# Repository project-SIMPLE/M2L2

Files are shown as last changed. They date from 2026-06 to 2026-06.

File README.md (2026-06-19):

# M2L2 — SIMPLE Project

**Mobile Metaverse Learning Lab (M2L2)** is an open-source, self-contained box housing VR headsets and a server, designed to make deploying immersive learning experiences in classrooms as simple as possible.

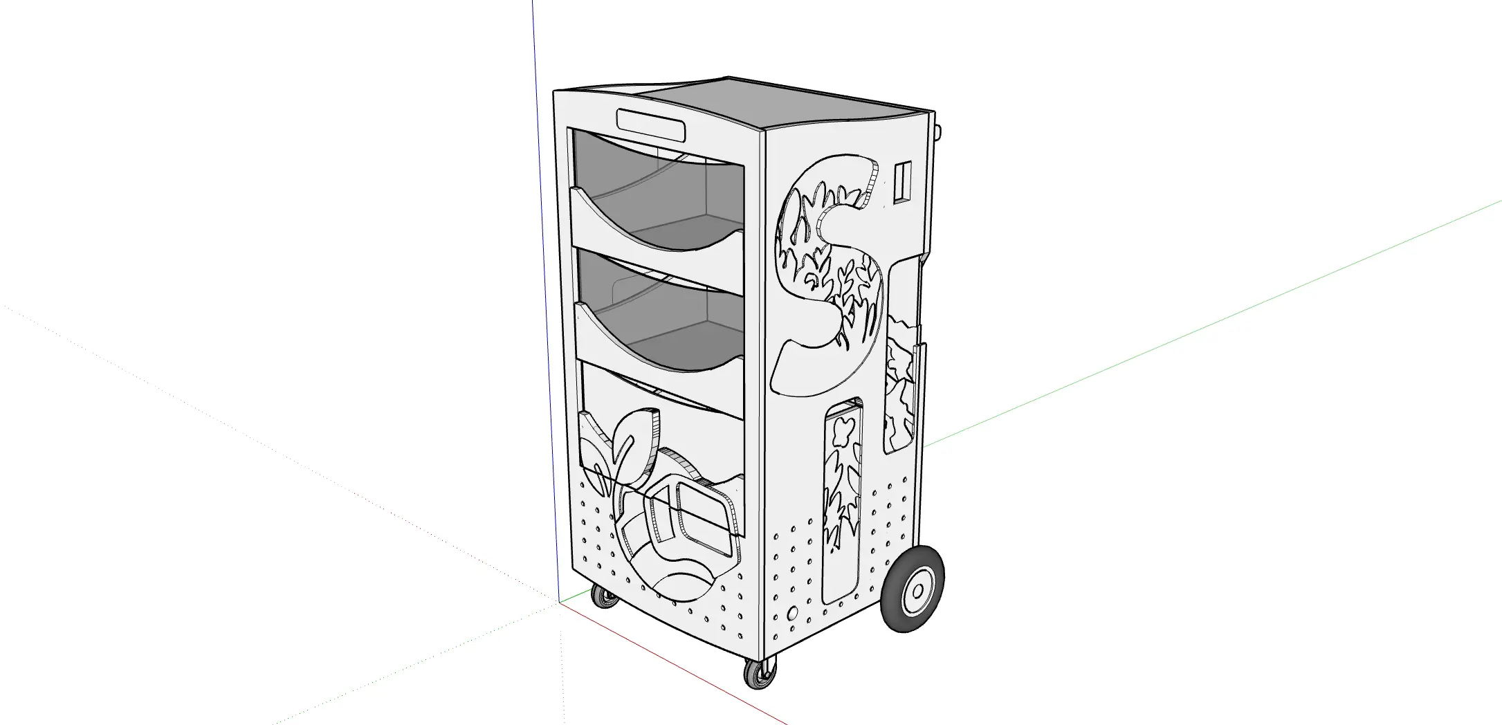
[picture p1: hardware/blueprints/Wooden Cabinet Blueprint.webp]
Blueprint view


---

## Repository Structure

```
m2l2/
├── hardware/ # Blueprints, BOM, assembly guides, and component specs
└── software/ # Mac Mini setup and configuration tools (zsh scripts, etc.)
```

- **[hardware/](./hardware/)** — Everything you need to build or replicate the physical M2L2 box.
- **[software/](./software/)** — Tools to provision the recommended Mac Mini to run the SIMPLE project.

---

## Getting Started

1. **Build the box** — Follow the [hardware guide](./hardware/README.md) to assemble your M2L2 unit.
2. **Set up the server** — Use the [software setup tools](./software/README.md) to configure the Mac Mini.
3. **Deploy** — You're ready to bring VR into the classroom!

---

## Contributing

Contributions are welcome! Please open an issue or submit a pull request. See [CONTRIBUTING.md](./CONTRIBUTING.md) for guidelines.

---

## Acknowledgments

The latest iteration of the M2L2 enclosure was designed and built by [Legacy Handmade](https://www.legacytayho.com/).

---

## License

This project is open-source. See [LICENSE](./LICENSE) for details.

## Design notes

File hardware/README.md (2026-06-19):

# Hardware — M2L2 Box

This folder contains all the hardware documentation required to build, replicate, or maintain the **M2L2** box — a self-contained unit housing VR headsets and a server, designed for easy deployment of the [SIMPLE project](https://github.com/project-simple) in classroom environments.

Blueprint view

---

## Folder Structure

```
hardware/
├── blueprints/ # Cabinet drawings and mechanical plans
├── bom/ # Bill of Materials (BOM)
└── assembly/ # Step-by-step assembly guide
```

---

## What's in the Box

The M2L2 box is designed to be a plug-and-play classroom kit. It typically includes:

- **VR Headsets** — Pre-configured for the SIMPLE project
- **Server (Mac Mini)** — Runs the SIMPLE project software
- **Networking equipment** — Local network switch/router for headset connectivity
- **Power distribution** — PDU or power strip for all devices
- **Enclosure** — The physical box housing all components

> Refer to the [BOM](./bom/) for exact part references, quantities, and sourcing.

---

## Blueprints

The [`blueprints/`](./blueprints/) directory contains the cabinet drawings and mechanical plans (dimensions, cutouts, internal layout):

- `Wooden Cabinet Blueprint.pdf`

> The latest M2L2 enclosure was designed and built by [Legacy Handmade](https://www.legacytayho.com/).

---

## Bill of Materials (BOM)

See [`bom/`](./bom/) for the full parts list including:

- Part names and descriptions
- Recommended suppliers and part numbers
- Quantities per unit
- Estimated costs

---

## Assembly

Step-by-step assembly instructions are in [`assembly/`](./assembly/README.md). The guide covers headset preparation, cabinet preparation, and the internal power/network/display wiring. Follow the sections in order to avoid rework.

---

## Notes

- Always power off the unit before performing any hardware maintenance.
- Ensure adequate ventilation around the Mac Mini to prevent thermal throttling.
- VR headsets should be stored in their designated slots to avoid cable damage.

---

## Contributing

If you improve the hardware design (better cable management, new enclosure version, etc.), please open a pull request with updated blueprints and a revised BOM. See the root [CONTRIBUTING.md](../CONTRIBUTING.md) for guidelines.

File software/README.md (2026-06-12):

# Software — Mac Mini Setup Tools

This folder contains configuration and setup tools for the **Mac Mini** recommended to run the [SIMPLE project](https://github.com/project-simple) as part of the M2L2.

> **This is not the SIMPLE project's application source code.**
> These are environment setup tools (shell scripts, dotfiles, etc.) to provision a Mac Mini from a clean macOS install into a ready-to-run SIMPLE project host.

---

## Folder Structure

```
software/
├── scripts/ # setup and startup scripts (.command)
│ ├── Installation_script.command
│ └── startup_script.command
├── docs/ # setup guides and troubleshooting
│ ├── macmini_configuration.md
│ ├── wifi_router_configuration.md
│ ├── headset_configuration.md
│ ├── installation_instructions.md
│ ├── startup_script_instructions.md
│ └── BE25_firmware_update.md
└── BE25_firmware_v1.7.bin # bundled router firmware
```

---

## Prerequisites

Before running any scripts, make sure you have:

- A **Mac mini** running a supported version of macOS (pinned to **Sequoia 15.7.5**; see [Mac mini configuration](./docs/macmini_configuration.md))
- An **admin user account**
- An active internet connection (for the initial package installs only — the deployed box runs offline)

---

## Quick Start

Provision the box in this order. Each step links to its detailed guide:

1. **Configure the WiFi router** — SSID, password, and firmware:
   [WiFi router configuration](./docs/wifi_router_configuration.md).
2. **Configure the Mac mini** — initial setup, app install, auto-start, and system settings:
   [Mac mini configuration](./docs/macmini_configuration.md).
   - Installs Homebrew, Node.js, ADB, and the WebPlatform via the [installation script](./docs/installation_instructions.md).
   - Sets the WebPlatform to launch on boot via the [startup script](./docs/startup_script_instructions.md).
3. **Configure the headsets** — developer mode, USB debugging, and fixed IPs:
   [Headset configuration](./docs/headset_configuration.md).

Once all three are done, the box boots straight into the WebPlatform player screen with all six headsets reachable on `M2L2_WIFI`.

---

## Contributing

Improvements to setup scripts are welcome! Please test changes on a clean macOS install before submitting a pull request. See the root [CONTRIBUTING.md](../CONTRIBUTING.md) for guidelines.

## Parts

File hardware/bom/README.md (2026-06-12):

# Bill of Materials — M2L2 Box

Complete parts list to build one **M2L2 (Mobile Metaverse Learning Lab)** unit: a self-contained, classroom-deployable kit running the [SIMPLE project](https://github.com/project-SIMPLE) stack.

> **Pricing note:** Prices are indicative (mid-2026). Big-ticket items in USD (US retail), locally sourced items in VND. Verify with your suppliers before ordering. Meta raised Quest 3 prices in April 2026; the 128GB model is discontinued.

---

### 1. Compute & VR

| # | Item | Ref / Model | Qty | Est. unit price | Subtotal | Notes |
|---|---|---|-----|---|---|---|
| 1.1 | VR headset | Meta Quest 3 — 512GB | 6 | $600 | $3,600 | Includes 2× Touch Plus controllers each. 512GB is the only variant since April 2026. |
| 1.2 | Head strap (+ battery) | BOBOVR M3 Pro | 6 | $40 | $240 | Halo strap with swappable B100 battery — comfort + extended runtime for back-to-back classroom sessions. The Carina D1 still charges the headset with the strap mounted, but **not** the strap battery (charge B100 packs separately via USB-C). |
| 1.3 | Server | Apple Mac mini (Apple Silicon, 16GB RAM / 512GB SSD min.) | 1 | $799 | $799 | Runs WebPlatform + GAMA + headset management. Pin macOS version per software setup guide (UPS control is OS-version sensitive). |
| 1.4 | Teacher tablet | Apple iPad (current base model, WiFi) | 1 | $349 | $349 | Client for the teacher dashboard (WebPlatform UI) over the local network. Any recent iPad works. |

### 2. Power

| # | Item | Ref / Model | Qty | Est. unit price | Subtotal | Notes |
|---|---|---|-----|---|---|---|
| 2.1 | UPS | APC Back-UPS BX2200MI-MS (2200VA / 1200W) | 1 | $250 | $250 | USB-HID monitored by the M2L2 UPS library for graceful shutdown. `-MS` = universal sockets variant. |
| 2.2 | Charging dock | PrismXR Carina D1 (Quest 3) | 6 | $80 | $480 | One dock per headset, charging at 30W. Each ships with its own fast-charge adapter and cable. Also charges Touch Plus controllers via contact pads (rechargeable batteries + contact battery covers included). |
| 2.3 | Power strip | Điện Quang ECO ĐQ ESK 5BR 8ECO — 8 outlets, 5m, 2500W max, breaker | 1 | 192.000 ₫ (~$8) | ~$8 | Plugs into UPS battery outlets; 8 slots and 2500W rating cover all 6 dock adapters + Mac mini + router simultaneously. Do **not** chain a surge protector behind the UPS. |
| 2.4 | USB-C cables | UGREEN US535 (90440) — USB-C to USB-C, 240W, 2m | 6 | $13 | $78 | ADB/management link to the Mac mini and backup wired charging. Any replacement must support ≥45W (headset max draw). |

### 3. Networking

| # | Item | Ref / Model | Qty | Est. unit price | Subtotal | Notes |
|---|---|---|-----|---|---|---|
| 3.1 | WiFi router | TP-Link Deco BE25 (WiFi 7) | 1 | $95 | $95 | Dedicated SSID for headsets. No internet uplink required — fully offline LAN. Ethernet cable for the Mac mini link is included in the box. |

### 4. Peripherals & Display

| # | Item | Ref / Model | Qty | Est. unit price | Subtotal | Notes |
|---|---|---|-----|---|---|---|
| 4.1 | USB-C hub | HyperDrive Next Dual 4K HDMI 7-in-1 | 1 | $150 | $150 | Used for its dual HDMI outputs (4K60 + 4K30) and its USB-A port, which connects the UPS USB-HID monitoring link to the Mac mini. |
| 4.2 | HDMI cables | UGREEN 10107 — HDMI, 2m | 2 | $10 | $20 | Internal runs: hub HDMI outputs enclosure panel couplers (4.3). |
| 4.3 | Keyboard + touchpad | Logitech K400 Plus Touch | 1 | $30 | $30 | Wireless all-in-one input for on-site Mac mini administration — no separate mouse or desk space needed. |

### 5. Enclosure & Mechanical

| # | Item | Ref / Model | Qty | Est. unit price | Subtotal | Notes |
|---|---|---|-----|---|---|---|
| 5.1 | Enclosure | **Custom build** — see [`blueprints/`](../blueprints/) | 1 | per blueprints | — | Materials, dimensions, and cutting plans are documented in the blueprints folder. Sized for the BX2200MI tower (~15kg) plus all components; total kit weight exceeds 25kg, plan for wheels/handles accordingly. |
| 5.2 | Cable management | Velcro straps, cable ties, adhesive mounts (assorted) | 1 | $15 | $15 | |
| 5.3 | Panel-mount plate | 3-slot wall-mount plate with 2× HDMI female (F/F) couplers | 1 | $12 | $12 | Mounted on the enclosure: exposes both HDMI outputs externally so the projector/screen plugs into the box without opening it. Third slot spare (blank or future port). |

## 6. Accessories & Consumables

| # | Item | Ref / Model | Qty | Est. unit price | Subtotal | Notes |
|---|---|---|-----|---|---|---|
| 6.1 | Hygiene face covers | Silicone facial interface cover (Quest 3 compatible) | 6 | $15 | $90 | Wipeable — required for shared classroom use. |
| 6.2 | Cleaning kit | Microfiber cloths + lens-safe wipes | 1 | $15 | $15 | Never use alcohol wipes on lenses. |
| 6.3 | Stickers | Custom-printed SIMPLE project stickers, numbered 1–6 | 1 set | $15 | $15 | Printed per project artwork. Headset number WebPlatform device identity; label headsets, controllers, and docks consistently. |

---

## Total estimated cost

| Category | Subtotal |
|---|---|
| 1. Compute & VR | $4,988 |
| 2. Power | $816 |
| 3. Networking | $95 |
| 4. Peripherals & Display | $212 |
| 5. Enclosure & Mechanical | $15 + custom enclosure (see blueprints) |
| 6. Accessories & Consumables | $120 |
| **Total per M2L2 unit** | **≈ $6,246 + enclosure materials** |

---

## Substitution guidance

- **Headsets** — the SIMPLE Unity template targets Meta Horizon OS; Quest 3S (128GB, $350) is a functional drop-in that cuts ~$1,500 per box at the cost of lens/resolution quality. Pair with the Carina **D1S** dock variant and the BOBOVR **S3** strap line. Lower-cost non-Meta alternatives are under active investigation (see project roadmap).
- **Server** — any Apple Silicon Mac mini works; avoid Intel models (UPS control library uses IOKit HID paths validated on Apple Silicon).
- **Power strip** — any 8-outlet strip rated ≥2500W with a breaker is acceptable; the Điện Quang reference is a locally sourced (Vietnam) part.
- **USB-C cables** — any e-marked USB-C cable supporting ≥45W works; 240W-rated cables chosen for headroom and durability.
- **Teacher tablet** — any device with a modern browser can run the dashboard; the iPad is the validated reference client.

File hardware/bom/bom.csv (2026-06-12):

id | category | item | model | qty | unit_price | currency | subtotal_usd_approx | notes
1.1 | Compute & VR | VR headset | Meta Quest 3 512GB | 6 | 600 | USD | 3600 | Includes 2x Touch Plus controllers each; 512GB only variant since April 2026
1.2 | Compute & VR | Head strap (battery) | BOBOVR M3 Pro | 6 | 40 | USD | 240 | Halo strap with swappable B100 battery; Carina D1 charges headset with strap mounted but not the strap battery
1.3 | Compute & VR | Server | Apple Mac mini (Apple Silicon; 16GB RAM / 512GB SSD min.) | 1 | 799 | USD | 799 | Runs WebPlatform + GAMA + headset management; pin macOS version per software setup guide
1.4 | Compute & VR | Teacher tablet | Apple iPad (current base model; WiFi) | 1 | 349 | USD | 349 | Client for the teacher dashboard over local network
2.1 | Power | UPS | APC Back-UPS BX2200MI-MS (2200VA / 1200W) | 1 | 250 | USD | 250 | USB-HID monitored for graceful shutdown; -MS = universal sockets
2.2 | Power | Charging dock | PrismXR Carina D1 (Quest 3) | 6 | 80 | USD | 480 | One dock per headset @30W; own adapter + cable included; charges controllers via contact pads (rechargeable batteries included)
2.3 | Power | Power strip | Dien Quang ECO DQ ESK 5BR 8ECO (8 outlets; 5m; 2500W; breaker) | 1 | 192000 | VND | 8 | Plugs into UPS battery outlets; covers all dock adapters + Mac mini + router; no surge protector behind UPS
2.4 | Power | USB-C cables | UGREEN US535 90440 (USB-C to USB-C; 240W; 2m) | 6 | 13 | USD | 78 | ADB/management + backup wired charging; replacement must support >=45W (headset max)
3.1 | Networking | WiFi router | TP-Link Deco BE25 (WiFi 7) | 1 | 95 | USD | 95 | Dedicated SSID for headsets; fully offline LAN; Ethernet cable included in box
4.1 | Peripherals & Display | USB-C hub | HyperDrive Next Dual 4K HDMI 7-in-1 | 1 | 150 | USD | 150 | Used for dual HDMI outputs (4K60 + 4K30) and USB-A port connecting the UPS USB-HID monitoring link to the Mac mini
4.2 | Peripherals & Display | HDMI cables | UGREEN 10107 (HDMI; 2m) | 2 | 10 | USD | 20 | Internal runs: hub HDMI outputs to enclosure panel couplers (4.3)
4.3 | Peripherals & Display | Keyboard + touchpad | Logitech K400 Plus Touch | 1 | 30 | USD | 30 | Wireless all-in-one input for on-site Mac mini administration
5.1 | Enclosure & Mechanical | Enclosure | Custom build - see blueprints/ | 1 |  |  |  | Materials and plans documented in blueprints folder; kit weight >25kg
5.2 | Enclosure & Mechanical | Cable management | Velcro straps + cable ties + adhesive mounts | 1 | 15 | USD | 15
5.3 | Peripherals & Display | Panel-mount plate | 3-slot wall-mount plate with 2x HDMI female (F/F) couplers | 1 | 12 | USD | 12 | Mounted on enclosure; exposes both HDMI outputs externally; third slot spare
6.1 | Accessories & Consumables | Hygiene face covers | Silicone facial interface cover (Quest 3 compatible) | 6 | 15 | USD | 90 | Wipeable; required for shared classroom use
6.2 | Accessories & Consumables | Cleaning kit | Microfiber cloths + lens-safe wipes | 1 | 15 | USD | 15 | No alcohol wipes on lenses
6.3 | Accessories & Consumables | Stickers | Custom-printed SIMPLE project stickers numbered 1-6 | 1 | 15 | USD | 15 | Headset number maps to WebPlatform device identity; label headsets/controllers/docks
TOTAL |  |  |  |  |  |  | 6246 | Approx USD mid-2026 excluding custom enclosure materials; verify regional pricing

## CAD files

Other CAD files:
hardware/blueprints/Wooden Cabinet Blueprint.skp

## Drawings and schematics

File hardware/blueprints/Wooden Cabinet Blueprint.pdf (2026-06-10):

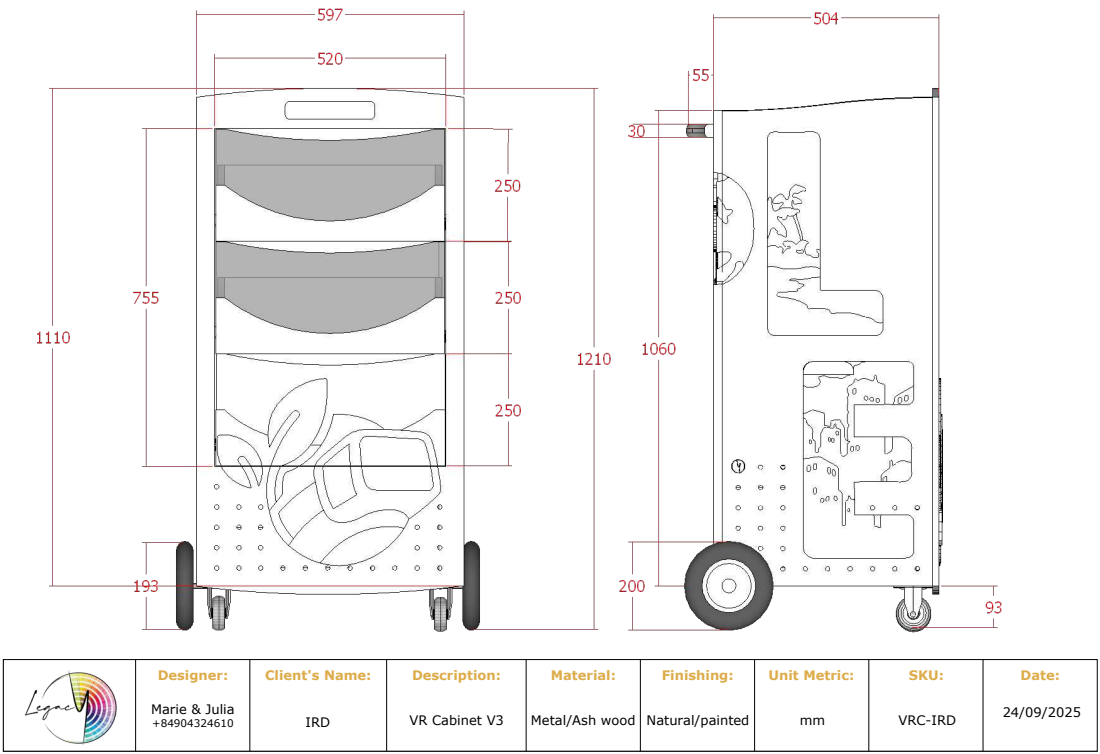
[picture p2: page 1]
Marie & Julia; Designer:; Client's Name:; Description:; Material:; Finishing:; Unit Metric:; SKU:; Date:; IRD; VR Cabinet V3; Metal/Ash wood; Natural/painted; VRC-IRD

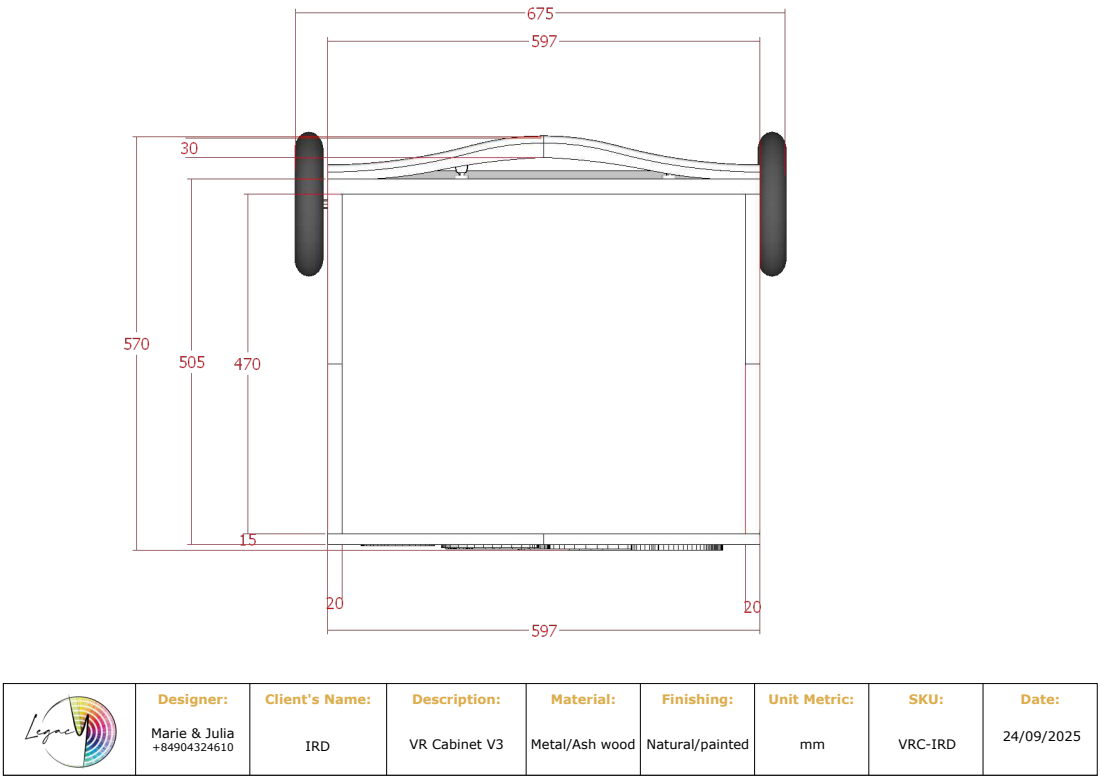
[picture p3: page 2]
Designer:; Client's Name:; Description:; Material:; Finishing:; Unit Metric:; SKU:; Date:

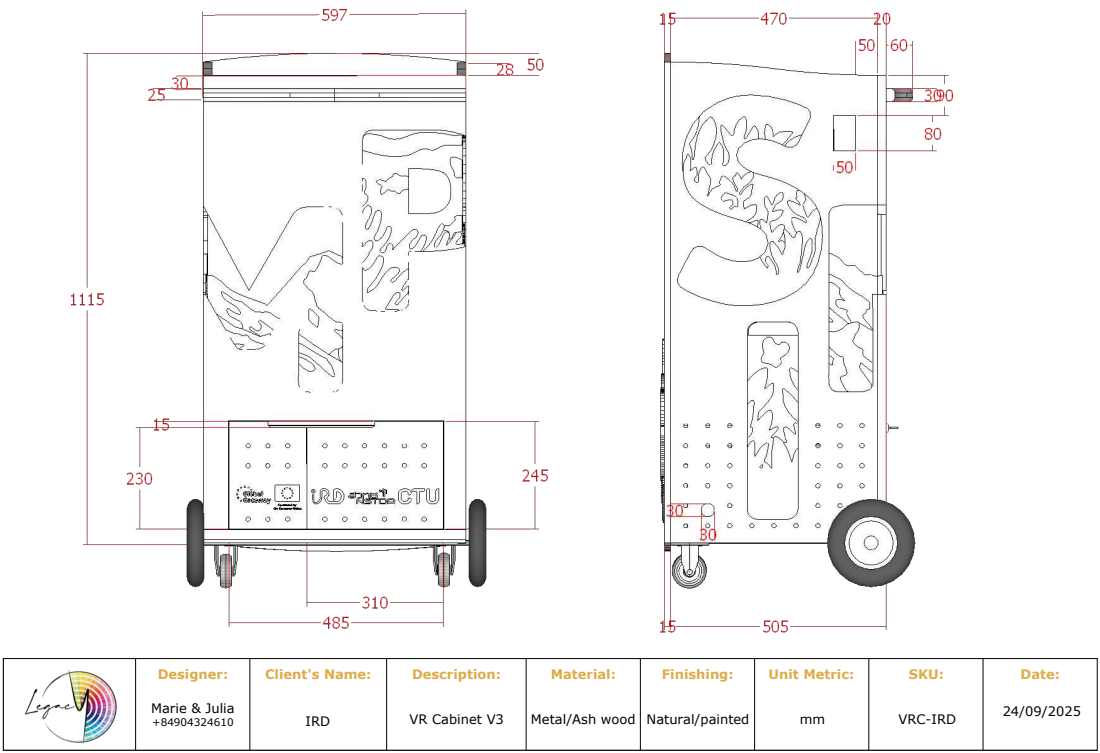
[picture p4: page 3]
Designer:; Client's Name:; Description:; Material:; Finishing:; Unit Metric:; SKU:; Date:

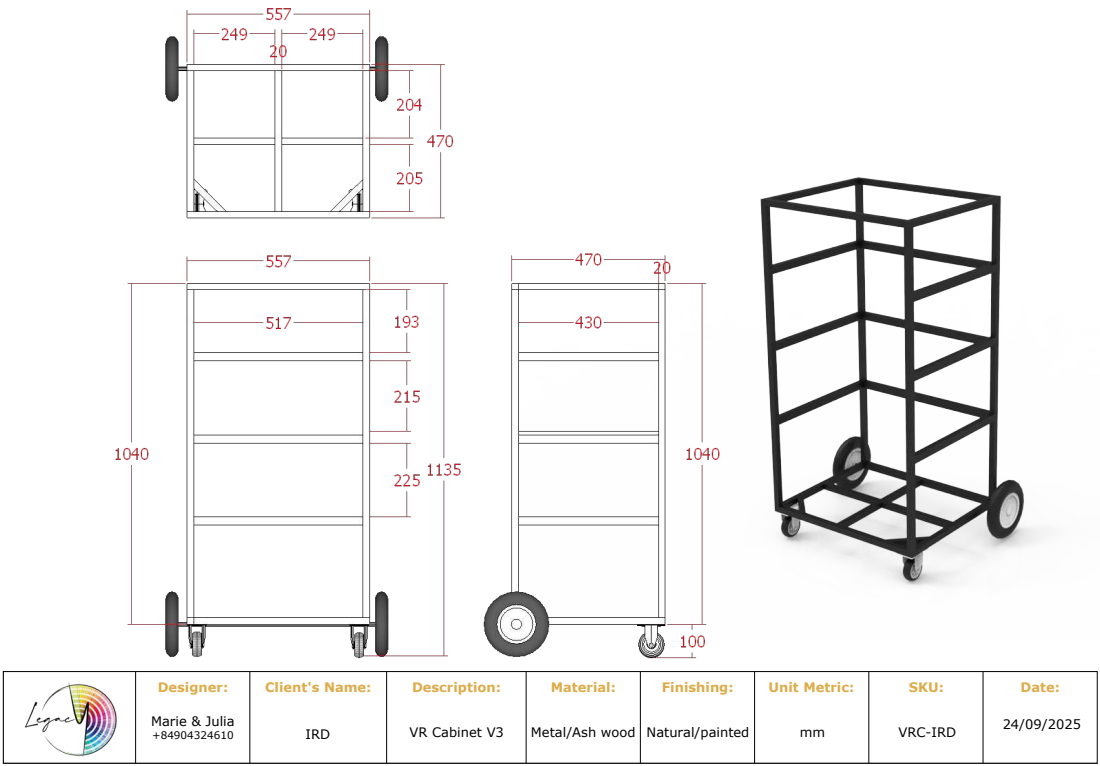
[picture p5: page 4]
Designer:; Client's Name:; Description:; Material:; Finishing:; Unit Metric:; SKU:; Date:

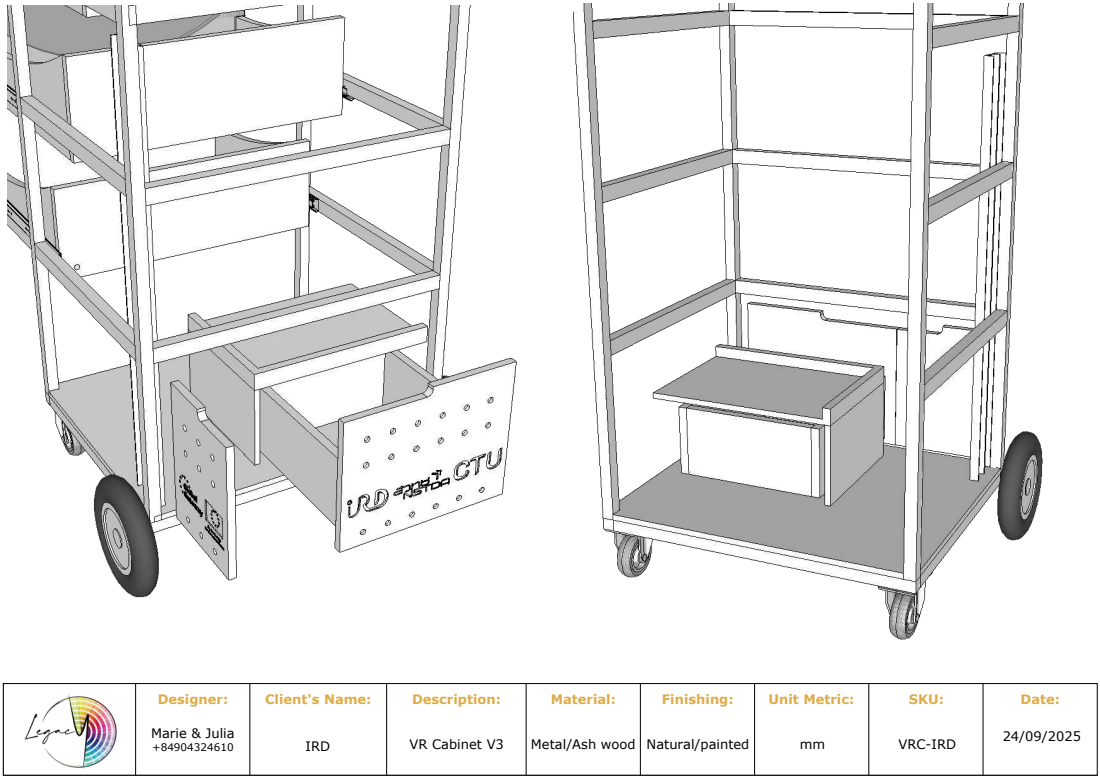
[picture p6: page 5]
Designer:; Client's Name:; Description:; Material:; Finishing:; Unit Metric:; SKU:; Date:

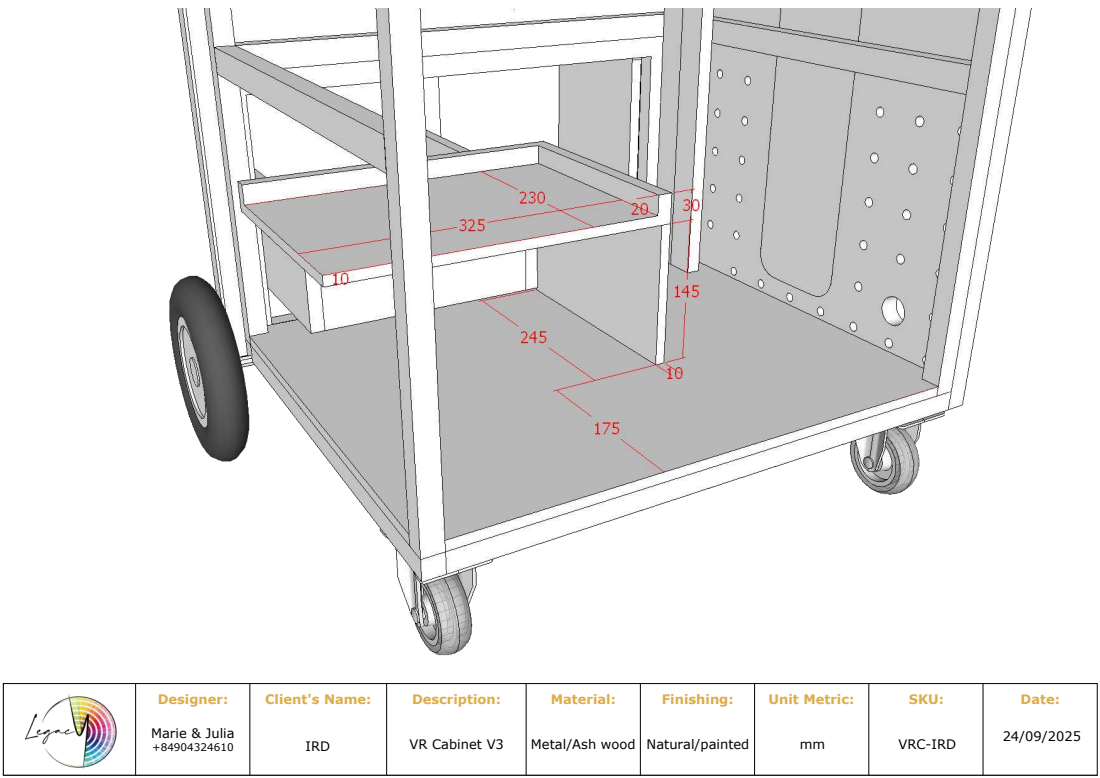
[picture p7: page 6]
Designer:; Client's Name:; Description:; Material:; Finishing:; Unit Metric:; SKU:; Date:

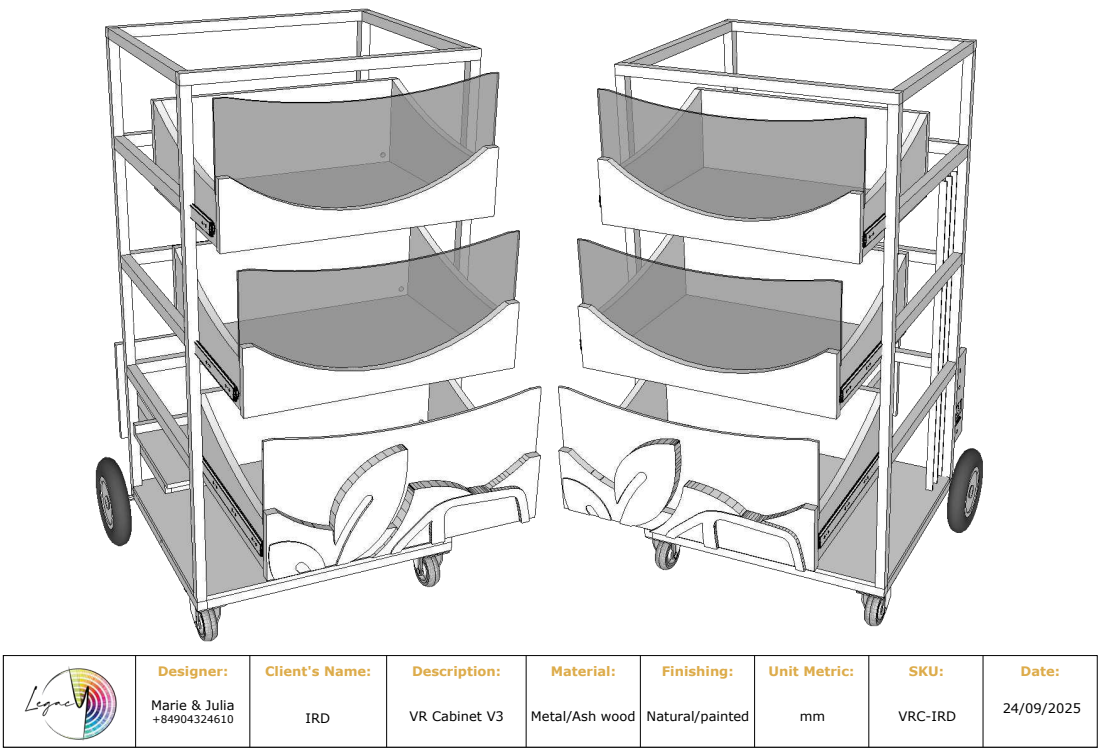
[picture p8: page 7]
Designer:; Client's Name:; Description:; Material:; Finishing:; Unit Metric:; SKU:; Date:

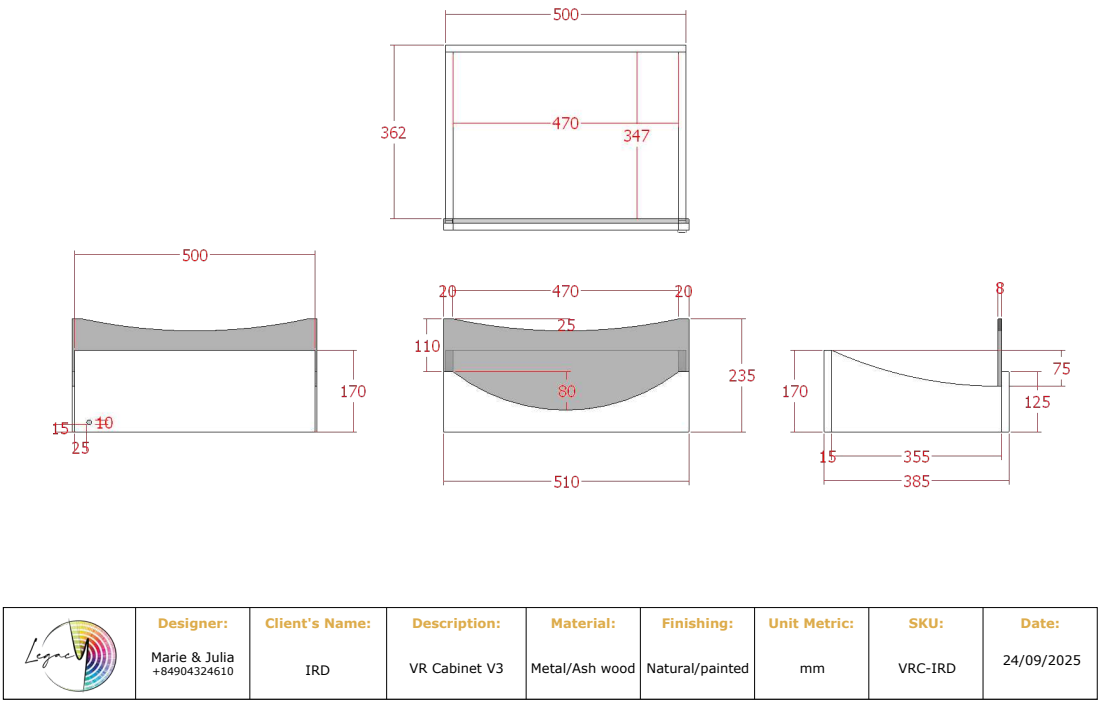
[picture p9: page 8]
Designer:; Client's Name:; Description:; Material:; Finishing:; Unit Metric:; SKU:; Date:

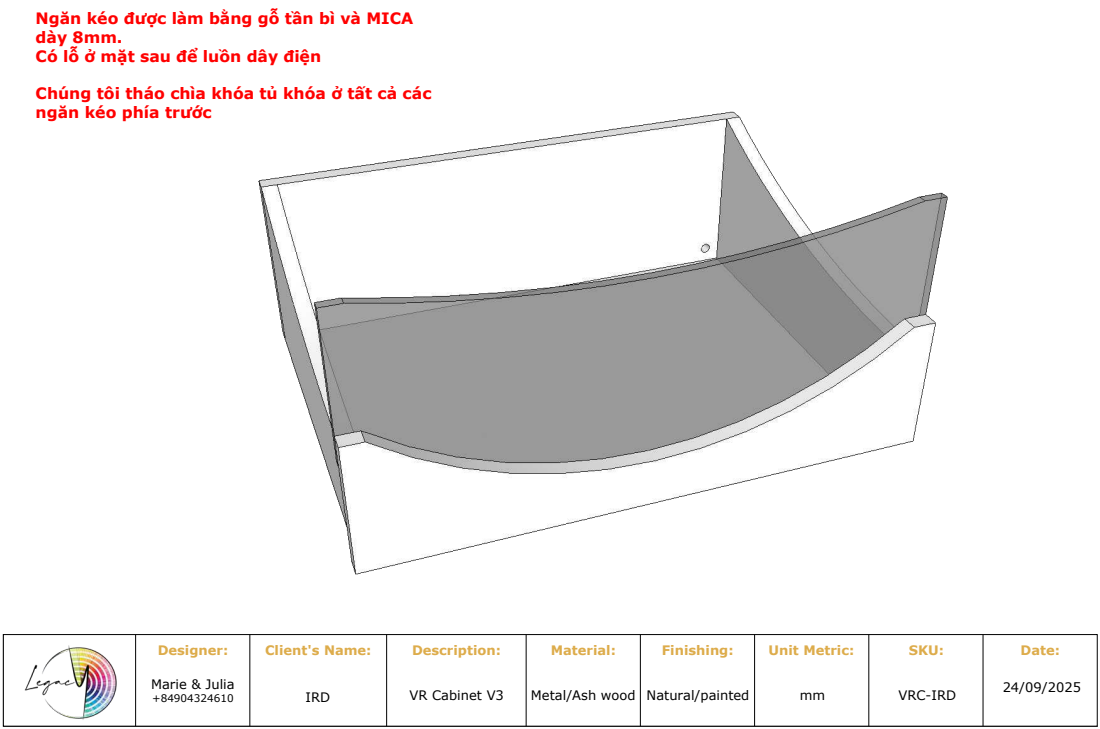
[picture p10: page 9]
Designer:; Client's Name:; Description:; Material:; Finishing:; Unit Metric:; SKU:; Date:

Ngăn kéo được làm bằng gỗ tần bì và MICA
dày 8mm.
Có lỗ ở mặt sau để luồn dây điện

Chúng tôi tháo chìa khóa tủ khóa ở tất cả các
ngăn kéo phía trước

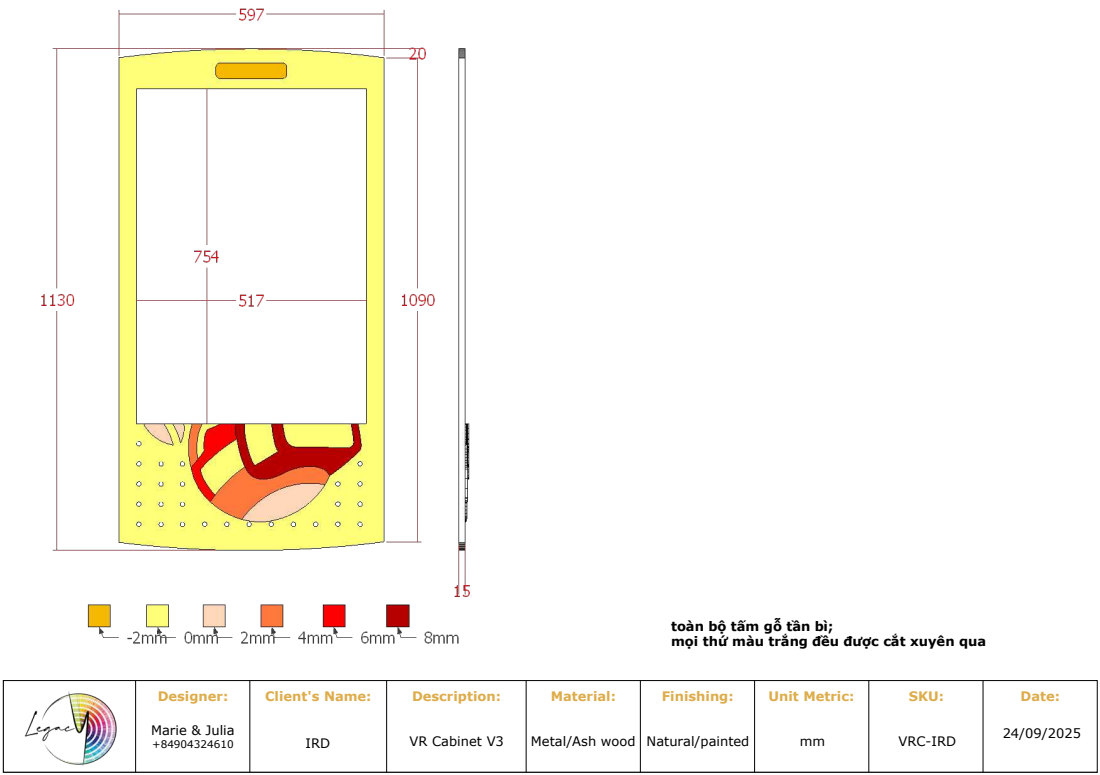
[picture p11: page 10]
Designer:; Client's Name:; Description:; Material:; Finishing:; Unit Metric:; SKU:; Date:

toàn bộ tấm gỗ tần bì;
mọi thứ màu trắng đều được cắt xuyên qua

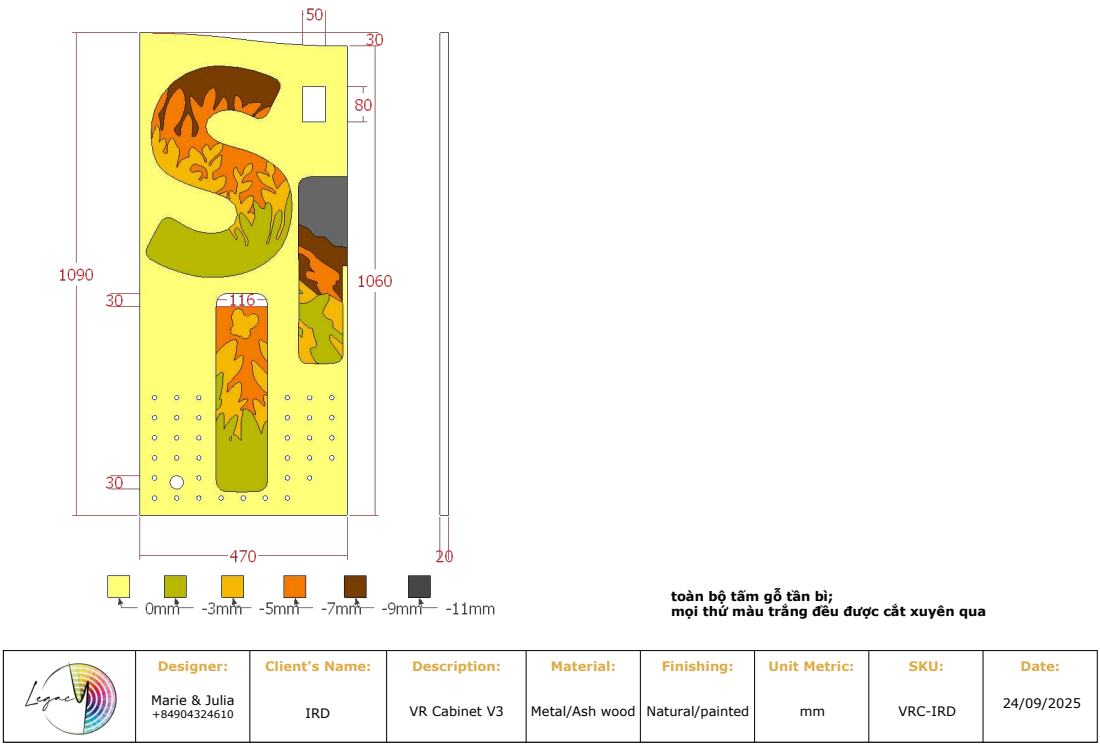
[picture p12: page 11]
Designer:; Client's Name:; Description:; Material:; Finishing:; Unit Metric:; SKU:; Date:

toàn bộ tấm gỗ tần bì;
mọi thứ màu trắng đều được cắt xuyên qua

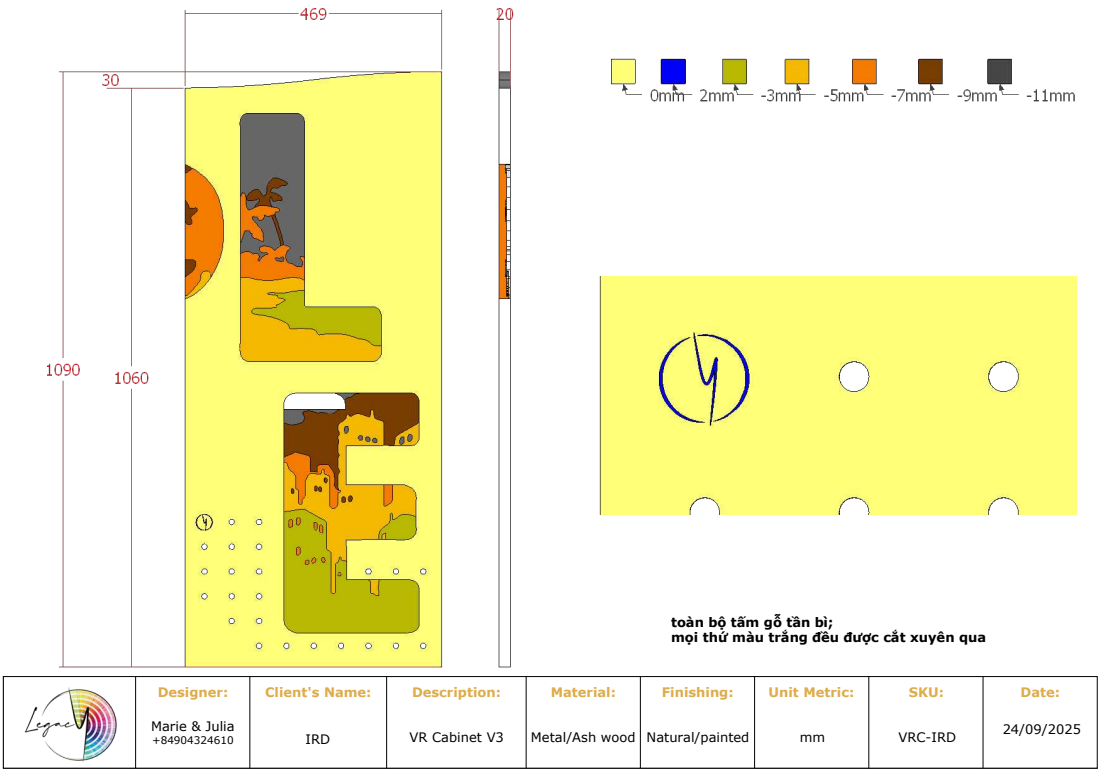
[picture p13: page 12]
Designer:; Client's Name:; Description:; Material:; Finishing:; Unit Metric:; SKU:; Date:

toàn bộ tấm gỗ tần bì;
mọi thứ màu trắng đều được cắt xuyên qua

Designer:; Client's Name:; Description:; Material:; Finishing:; Unit Metric:; SKU:; Date:

toàn bộ tấm gỗ tần bì;
mọi thứ màu trắng đều được cắt xuyên qua

chi tiết của một bề mặt góc để đẩy xe đẩy
tủ và sử dụng các bánh xe mà không làm
hỏng đáy/ detail of an angle surface to
push on the cabinet trolley and use the
wheels without damaging the bottom

Designer:; Client's Name:; Description:; Material:; Finishing:; Unit Metric:; SKU:; Date:

Designer:; Client's Name:; Description:; Material:; Finishing:; Unit Metric:; SKU:; Date:

hệ thống tủ khóa bằng gỗ

Designer:; Client's Name:; Description:; Material:; Finishing:; Unit Metric:; SKU:; Date:

Designer:; Client's Name:; Description:; Material:; Finishing:; Unit Metric:; SKU:; Date:

Designer:; Client's Name:; Description:; Material:; Finishing:; Unit Metric:; SKU:; Date:

Designer:; Client's Name:; Description:; Material:; Finishing:; Unit Metric:; SKU:; Date:

mặt trước của ngăn kéo phía trước bằng cnc

Designer:; Client's Name:; Description:; Material:; Finishing:; Unit Metric:; SKU:; Date:

Designer:; Client's Name:; Description:; Material:; Finishing:; Unit Metric:; SKU:; Date:

Designer:; Client's Name:; Description:; Material:; Finishing:; Unit Metric:; SKU:; Date:

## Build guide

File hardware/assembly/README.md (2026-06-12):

# Assembly — M2L2 Box

This guide walks through assembling one **M2L2** unit end to end: preparing the six VR headsets, fitting out the wooden cabinet, and wiring the internal power, network, and display chain. Follow the sections in order — headset preparation and cabinet wiring are independent, but the electrical install assumes the cabinet has already been checked.

> This is the **physical** build. Once the box is wired, move on to the [software setup](../../software/README.md) to provision the Mac mini, router, and headsets.

Refer to the [Bill of Materials](../bom/README.md) for exact part references and quantities, and to [`blueprints/`](../blueprints/) for the cabinet dimensions and cutouts.

---

## Before you start

Lay out the full kit and confirm every item from the [BOM](../bom/README.md) is present. You should have, per unit:

- 6× Meta Quest 3 headsets (2 controllers each)
- 6× BOBOVR M3 Pro head straps (with B100 batteries)
- 6× PrismXR Carina D1 charging docks (adapters, cables, controller interfaces, special rechargeable batteries)
- 1× Mac mini + charge cable, 1× USB-C hub, 2× HDMI cables
- 1× APC Back-UPS BX2200MI + USB cable
- 1× 8-outlet power strip
- 1× TP-Link Deco BE25 router + power cable
- 1× wireless keyboard (dongle, batteries), 1× iPad (optional)
- 1 sheet of numbered stickers

> Power off and unplug everything before working inside the cabinet.

---

## 1. Headset preparation

Repeat every step in this section for all **6** headsets.

### 1.1 Install the BOBOVR M3 Pro head strap

Replace the stock Quest 3 strap with the BOBOVR M3 Pro halo strap and seat the B100 battery on the rear cradle. Follow the manufacturer's mounting guide:

- <https://www.bobovr.com/products/bobovr-m3-pro>

The M3 Pro improves comfort for back-to-back classroom sessions and adds runtime via the swappable rear battery.

### 1.2 Install the PrismXR Carina D1 charging interface

1. Install the **magnets** on the headset and controllers.
2. Prepare the **controllers**: the magnetic supports and the special rechargeable batteries are supplied in the PrismXR box. Fit them to each controller.
3. Mount the headset interface, using the PrismXR positioning guide to place the **magnetic hook** correctly so the headset docks cleanly.
4. Set the **facial interface** to its maximum (furthest) position so the headset can be worn over glasses.

### 1.3 Apply the stickers

Each headset is identified by a number (1–6) that must match across the headset, its controllers, and its dock. Apply the matching sticker set:

- **1** main sticker on the headset
- **1** secondary sticker per controller (2 total)
- **3** stickers on the sides of the BOBOVR strap

> The sticker number maps to the headset's identity in the WebPlatform and to its assigned IP address during [headset configuration](../../software/docs/headset_configuration.md). Keep numbering consistent.

---

## 2. Cabinet preparation

Before wiring anything, check the cabinet's pre-routed cables.

1. Verify that **each drawer holds two cables** of the correct length (one pair per drawer for the two PrismXR docks it will hold).

> **Top drawer cables:** if the cables in the top drawer do not reach the back when the drawer is fully open, gently pull them to feed more cable down from the electrical column until you have the required length.

---

## 3. Electrical and internal wiring

Work from the bottom of the cabinet upward.

1. **Arm the UPS** — set the APC Back-UPS battery contact (connect the internal battery terminal).
2. **Make room** — remove the bottom headset drawer to access the base of the cabinet.
3. **Install the UPS** in the base and route its power cable out through the dedicated hole.
4. **Connect the power strip** to the UPS battery-backed outlets.
5. **Wire the charging docks** — use the dock adapters to connect the **6 USB-C dock cables** to the power strip.
6. **Distribute the docks** — install **2 PrismXR Carina D1 stations per drawer**, connecting each to the USB cables pre-routed in that drawer.
7. **Install the Mac mini:**
   - Plug the Mac mini power adapter into the power strip.
   - Connect the **USB-C hub** to the Mac mini.
   - Plug the **two HDMI cables** from the cabinet's external panel into the hub's HDMI outputs.
   - Connect the **UPS USB cable** to a USB-A port on the hub (this is the monitoring link used for graceful shutdown).
   - Set the Mac mini in its dedicated spot.
8. **Install the WiFi router** — power the TP-Link Deco BE25 from the power strip and place it in its dedicated spot next to the Mac mini.
9. **Refit the bottom drawer** once routing is clear.

> Bundle slack cable with the velcro straps and adhesive mounts from the BOM so drawers slide freely and nothing is pinched.

---

## After assembly

The box is now physically complete. Continue with software provisioning:

1. [Configure the Mac mini](../../software/docs/macmini_configuration.md) — initial setup, WebPlatform install, auto-start, system settings.
2. [Configure the WiFi router](../../software/docs/wifi_router_configuration.md) — SSID, password, firmware.
3. [Configure the headsets](../../software/docs/headset_configuration.md) — developer mode, ADB authorization, IP assignment.

---

## Maintenance notes

- Always power off the unit before any hardware maintenance.
- Keep ventilation around the Mac mini clear to avoid thermal throttling.
- Store headsets in their designated drawer slots to avoid cable damage.

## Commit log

2026-04-20 ajout de la feature qui copie automatiquement le .env.example en .env, étape sautée si le .env existe déjà
2026-06-11 feat: Add BOM hardware listing
    [bom.csv]
2026-06-12 fixup! feat: Add BOM hardware listing Add missing equipments - BOBOVR - Teacher's iPad - HDMI cables - USB-C Dock etc
    [bom.csv]
2026-06-12 feat(hardware): Add Assembly documentation As well as cleaning emojis and style from the other files
2026-06-15 feat(blueprint): Add 3d files of the wooden cabinet
    [Wooden Cabinet Blueprint.skp]
